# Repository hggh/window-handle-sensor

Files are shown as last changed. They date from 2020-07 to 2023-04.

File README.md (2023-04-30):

### window handle sensor

get the status of your windows. sensor is between your handle and the window.

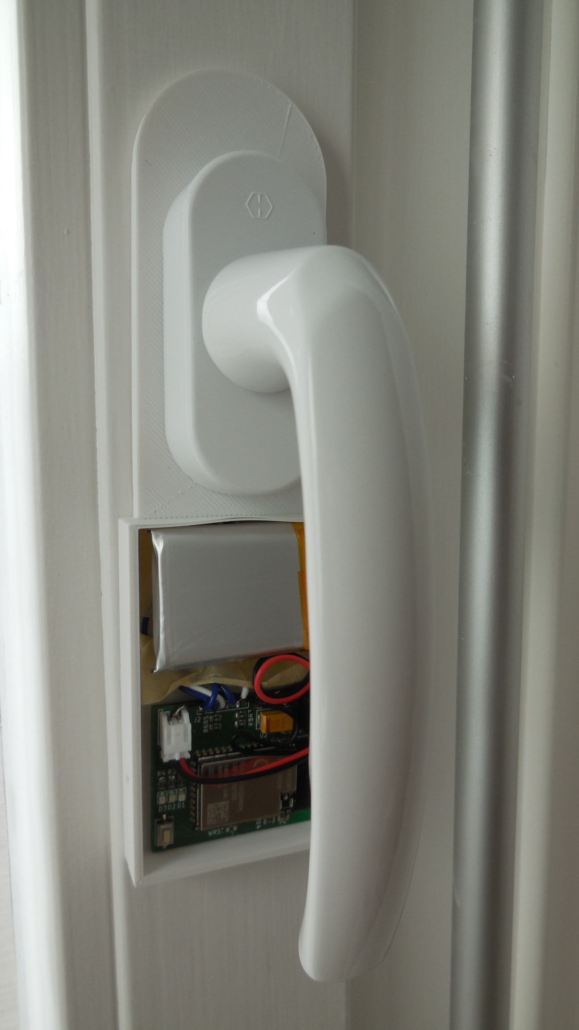
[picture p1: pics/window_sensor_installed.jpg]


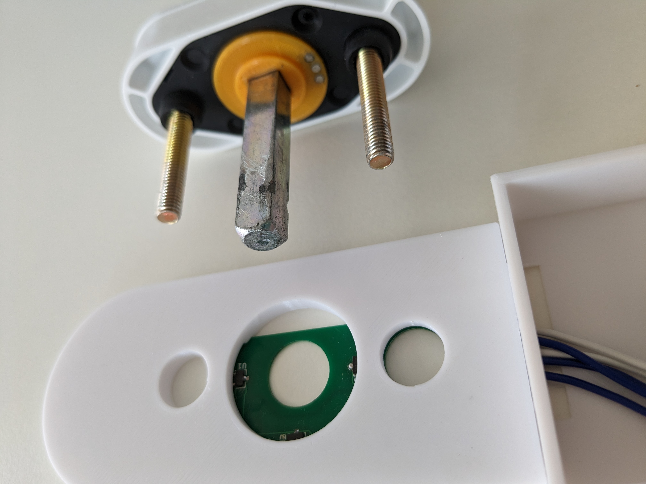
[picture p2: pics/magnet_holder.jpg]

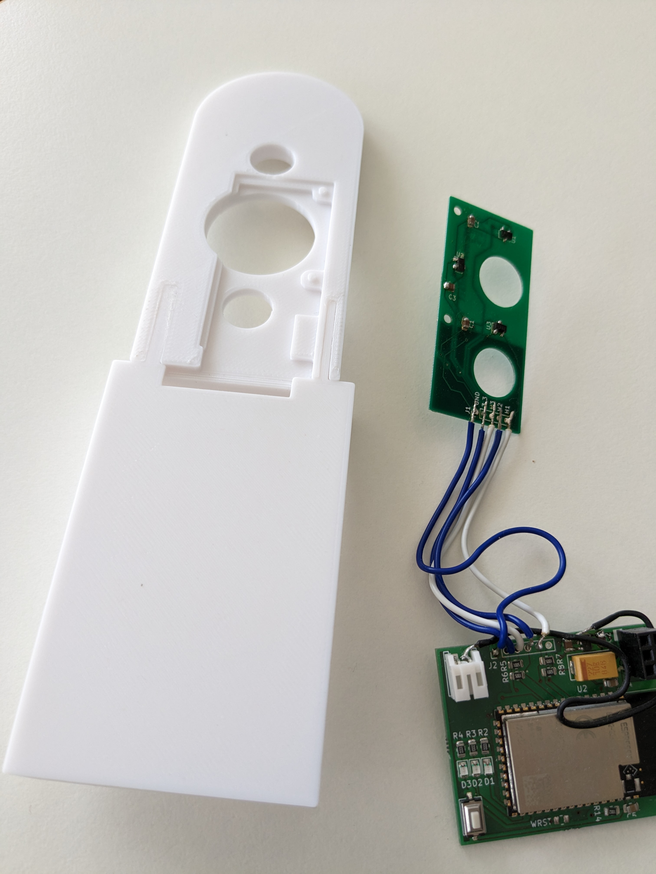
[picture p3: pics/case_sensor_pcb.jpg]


### TODO

 * replace xc6220 footprint with the one from KiCAD
 * add a button for wifi reset
 * battery connector rotate it: open should be on top

### PCBs

this project contains of two pcbs.

#### window-handle-sensor

This PCB is the sensor. It has three hall sensors placed on a **0.6mm** pcb.

library used: https://github.com/hggh/kicad-libraries

##### BOM of window-handle-sensor pcb

| number | name |
|---| ---|
| C1,C2,C3 | ceramic cap 0.1 µF SMD 0805 |
| U1,U2,U3 | Infineon TLE4913 |

#### ESP controller board

This PCB is the controller board with the ESP32-S2. The thickness of this pcb can be 1.0-1.6mm.

##### BOM of esp32-s2 pcb

| number | name |
|--- | ---|
| C1 | ceramic cap 22µF SMD 0805 |
| C2 | ceramic cap 4.7µF SMD 0805 |
| C3 | tantalum cap 220µF SMD EIA-7343-31 |
| C4 | ceramic cap 100nF SMD 0805 |
| C5 | ceramic cap 1µF SMD 0805 |
| U1 | XC6220 3.0V SOT-25 |
| U2 | ESP32-S2-WROOM |
| H1 | 2.54mm 2x3 pin header |
| J1 | JST PH S2B-PH-K |
| Q1 | BC817 |
| Q2 | BC807 |
| R1, R14 | 10k SMD0805 |
| R2, R3, R4 | 100 SMD0805 |
| R5, R6, R7, R8, R9 | 10M SMD 0805 |
| R10, R11 | 1k1 SMD 0805 |
| R12, R13 | 10k SMD 0805 |

### case

The inlay is placed on the square bolt with 3x magnets.

Magnets: Ø 2 mm, h=1mm (strength: 110g): https://www.supermagnete.de/eng/disc-magnets-neodymium/disc-magnet-2mm-1mm_S-02-01-N

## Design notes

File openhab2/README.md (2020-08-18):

### OpenHAB2 integration

OpenHAB2 2.4 and later are required!

### install plugins

for the OpenHAB2 integration you will need to install the OpenHAB2 plugins (e.g. via paperui)

* MQTT Binding

#### install files into OpenHAB2 installation

```
cp *.items items/
cp *.map transform/
cp *.rules rules/
cp *.things things/
 ```
 
#### configuration

open **rules/window-state.things** and configure *host*, *username* and *password* parameter.

For every new Window state device you need:
 
 * **rules/window-state.things**: copy the "Thing topic window1" block and count the number "1" up. Also replace the "1" in the *stateTopic*!
 * **items/window-state.items**: copy the last three lines and also count the number "1" up. Do not rename the Item names. They are needed for the rules. But update the label of the item.
 
 The rules are based on the Item Groups - every Item that is also placed in the same groups all alarm rules will work on the fly! 
 
 Inside the **rules(window-state.rules** file you can configure how you will be notified if the battery is low or the device was not active within the last 25 hours.
 See line 49 and 63 inside the rules file. If you want to use Telegram, please install the Telegram plugin and configure your bot and enable the lines.

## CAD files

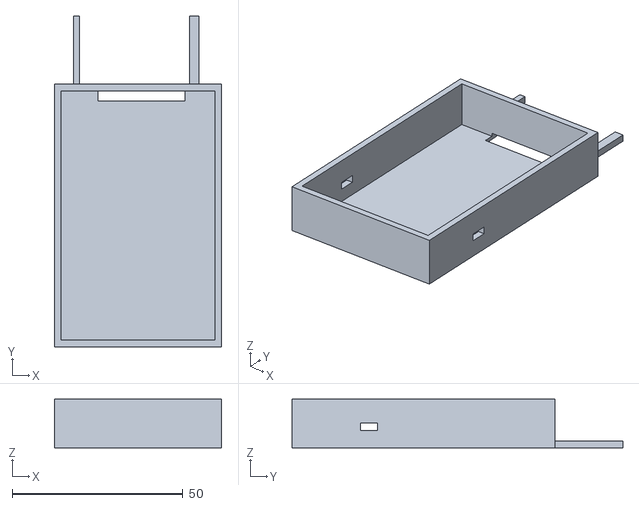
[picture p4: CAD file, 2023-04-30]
case/case_battery.stl
49.0 x 96.9 x 14.2

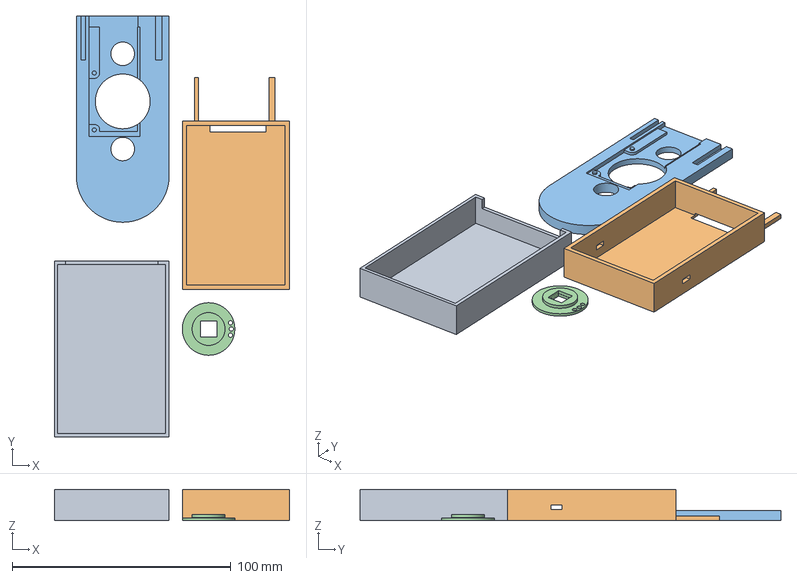
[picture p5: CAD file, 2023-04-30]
case/case.3mf
107.4 x 192.3 x 14.2 mm
battery_lid.stl
case_battery.stl
case_top.stl
inlay.stl

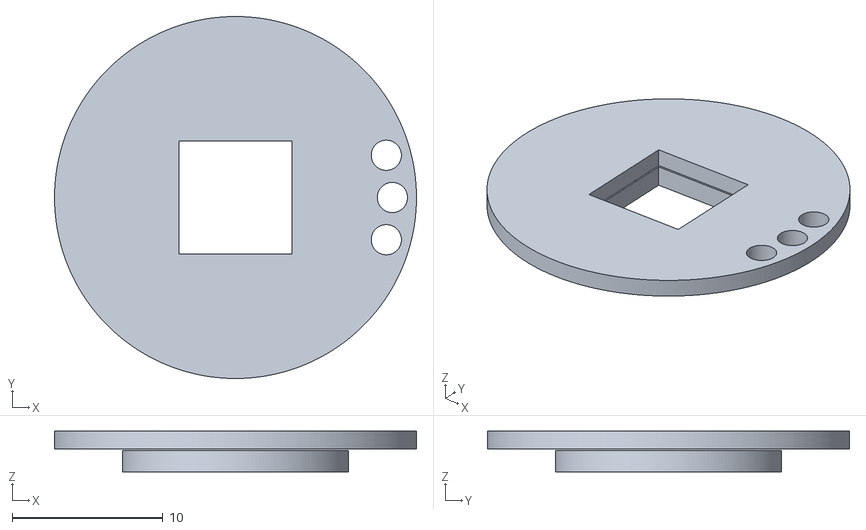
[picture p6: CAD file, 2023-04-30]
case/inlay.stl
24.0 x 24.0 x 2.70

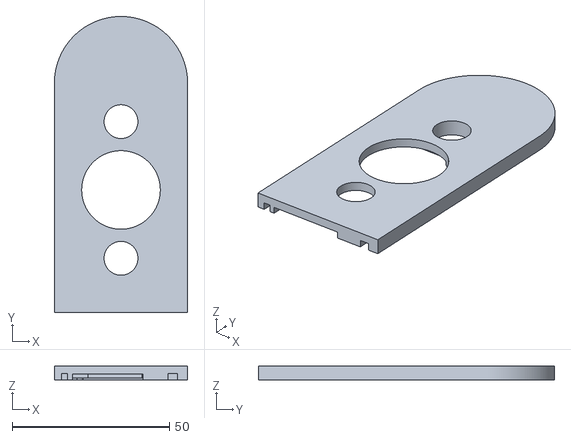
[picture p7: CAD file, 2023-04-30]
case/case_top.stl
42.4 x 94.2 x 4.50

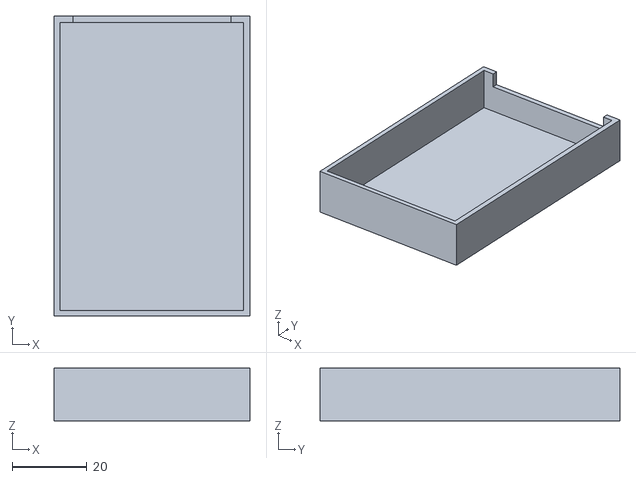
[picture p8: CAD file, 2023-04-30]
case/battery_lid.stl
52.4 x 80.4 x 14.2

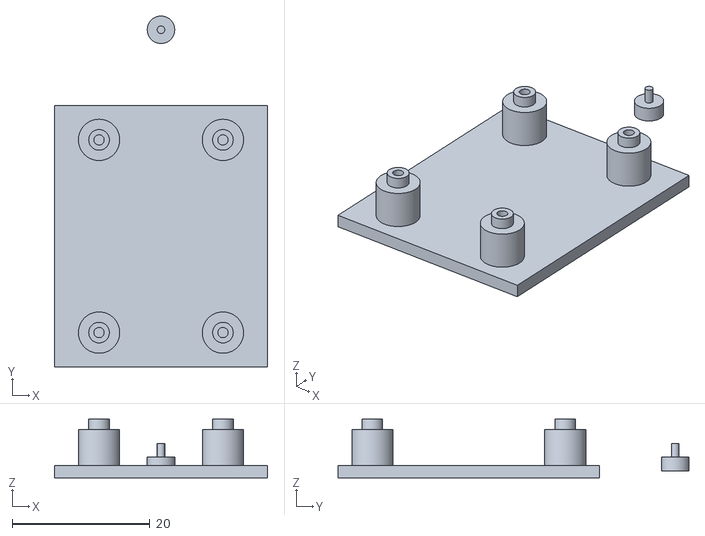
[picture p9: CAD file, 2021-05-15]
case/lipo-loader.stl
31.0 x 51.0 x 8.50

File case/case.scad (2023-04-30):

VIERKANT = 7.5;
CASE_SIZE_X = 40;
CASE_SIZE_Y = 68;
BOHRUNG_ABSTAND_MITTE = 21.75;
BOHRUNGEN = 10.75;

PCB_SIZE_X = 23.5;
PCB_SIZE_Y = 50;
PCB_SIZE_Z = 0.6 + 0.1;
PCB_SIZE_PARTS_Z = 1.2;

INLAY_HEIGHT_SPACING_Y = 1.4;
INLAY_HEIGHT_HOLDER_MAGNET_Y = 1.2;

CASE_SIZE_Z = PCB_SIZE_Z + INLAY_HEIGHT_SPACING_Y + INLAY_HEIGHT_HOLDER_MAGNET_Y;

BATTERY_BOX_X = 45 + 2 + 2;
BATTERY_BOX_Y = 75 + 2;
BATTERY_BOX_Z = 13;

LID_BATTERY_BOX_X = BATTERY_BOX_X + 1.6 + 1.6 + 0.1 + 0.1;
LID_BATTERY_BOX_Y = BATTERY_BOX_Y + 1.6 + 1.6 + 0.1 + 0.1;
LID_BATTERY_BOX_Z = BATTERY_BOX_Z + 1.2;


module pcb() {
    cube([PCB_SIZE_X, PCB_SIZE_Y, PCB_SIZE_Z+1]);
    // PCB the SMD stuff on front
    
    cube([22.25, PCB_SIZE_Y-2.25, PCB_SIZE_Z + PCB_SIZE_PARTS_Z+1]);
    translate([0, -5, 0]) cube([22.5, 5, PCB_SIZE_Z + PCB_SIZE_PARTS_Z+1]);
}

module inlay() {
	difference(){
        union() {
            cylinder(h=INLAY_HEIGHT_SPACING_Y, r=7.5, $fn=180);
            translate([0, 0, 1.5]) {
                cylinder(h=INLAY_HEIGHT_HOLDER_MAGNET_Y, r=12, $fn=180);
            }
        }
		cube([VIERKANT, VIERKANT, 10], center=true);
		translate([10.4, 0, -1]) {
			cylinder(h=20, d=2, $fn=180);
		}
        translate([10.0, 2.8, -1]) {
			cylinder(h=20, d=2, $fn=180);
		}
        translate([10.0, -2.8, -1]) {
			cylinder(h=20, d=2, $fn=180);
		}
	}
}

module lid() {

    difference() {
        cube([LID_BATTERY_BOX_X, LID_BATTERY_BOX_Y, LID_BATTERY_BOX_Z]);
        translate([1.6 - 0.1, 1.6 - 0.1, 1.2]) {
            cube([BATTERY_BOX_X + 0.1 + 0.1, BATTERY_BOX_Y + 0.1 + 0.1, 20]);
        }
        translate([(LID_BATTERY_BOX_X/2 - (CASE_SIZE_X + 2.4)/2), LID_BATTERY_BOX_Y-2, LID_BATTERY_BOX_Z - (CASE_SIZE_Z + 1.2) ]) {
            cube([CASE_SIZE_X + 2.4, 20, 20]);
        }
    }
}

module box_pcb_battery() {
    // innen: 45mm x 75mm
    difference() {
        cube([BATTERY_BOX_X, BATTERY_BOX_Y, LID_BATTERY_BOX_Z]);
        translate([2, 2, 1]) {
            cube([45, 73, LID_BATTERY_BOX_Z]);
        }
        translate([BATTERY_BOX_X/2 - PCB_SIZE_X/2, BATTERY_BOX_Y - 5, 0]) {
            cube([PCB_SIZE_X+2, 6, 2]);
        }
        translate([-1, 20, 5]) {
            cube([100, 5, 2.2]);
        }
        
    }
    translate([BATTERY_BOX_X/2, BATTERY_BOX_Y, 0]) {
        translate([15+0.1, 0, 0]) cube([3-0.2, 20-0.1, 2]);
        translate([-19+0.1, 0, 0]) cube([2-0.2, 20-0.1, 2]);
    }
    
}


module case_top() {
    difference() {
        union() {
            translate([0, CASE_SIZE_Y/2, 0]) {
                cylinder(h=CASE_SIZE_Z + 1.2, d=CASE_SIZE_X + 2.4, $fn=190);
            }
            translate([-(CASE_SIZE_X/2)-1.2, -(CASE_SIZE_Y/2) -5 , 0]) {
                cube([CASE_SIZE_X + 2.4, CASE_SIZE_Y+5, CASE_SIZE_Z + 1.2]);
            }
        }
        
        // Bohrung Mitte
        translate([0, 0, -1]) cylinder(h=10, d=25, $fn=180);
        // Bohrung Oben
        translate([0, BOHRUNG_ABSTAND_MITTE, -1]) cylinder(h=10, d=BOHRUNGEN, $fn=180);
        // Bohrung Unten
        translate([0, - BOHRUNG_ABSTAND_MITTE, -1]) cylinder(h=10, d=BOHRUNGEN, $fn=180);


        translate([-15.5, -34, -1]) {
            pcb();
        }
        
        // Ankerpunkte Batterie PCB Box
        translate([0, -(CASE_SIZE_Y/2) -5, 0]) {
            translate([15, 0, 0]) cube([3, 20, 2 +0.1]);
            translate([-19, 0, 0]) cube([2, 20, 2+0.1]);
        }
    }
    
    translate([-15.5, -34, 0]) {
        translate([0, 0, PCB_SIZE_Z]) {
            cube([5, 21, PCB_SIZE_PARTS_Z]);
        }
    }
    // haltepunkte PCB
    translate([-13, 13, 0]) {
        cylinder(h=CASE_SIZE_Z, d=1.9, $fn=180);
        translate([0, 0, PCB_SIZE_Z]) {
            cylinder(h=CASE_SIZE_Z-PCB_SIZE_Z, d=5, $fn=190);
            translate([-5, -2.5, 0]) cube([5, 5, CASE_SIZE_Z-PCB_SIZE_Z]);
        }
    }
    translate([-13, -13, 0]) {
        cylinder(h=CASE_SIZE_Z, d=1.9, $fn=180);
        translate([0, 0, PCB_SIZE_Z]) {
            cylinder(h=CASE_SIZE_Z-PCB_SIZE_Z, d=5, $fn=180);
            
            translate([-5, -2.5, 0]) cube([5, 5, CASE_SIZE_Z-PCB_SIZE_Z]);
        }
    }

}



translate([50, 10, 0]) {
    inlay();
}

translate([0, 10, 0]) {
    case_top();
}


translate([100, 0, 0]) {
    box_pcb_battery();
}

translate([155, -1.6, 0]) {
    lid();
}

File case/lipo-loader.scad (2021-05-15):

$fn = 190;

module holder() {
    difference() {
        union() {
            cylinder(d=6, h=6);
            cylinder(d=3, h=7.5);
        }
        
        translate([0, 0, 5]) {
            cylinder(d=1.5, h=10);
        }
    }
}

module pin() {
    cylinder(h=2, d=4);
    cylinder(d=1.1, h=4);
}


translate([-15.5, -19, -1]) {
    cube([31, 38, 1.8]);
}
translate([9, 14, 0]) holder();
translate([9, -14, 0]) holder();
translate([-9, 14, 0]) holder();
translate([-9, -14, 0]) holder();

translate([0, 30, 0]) pin();

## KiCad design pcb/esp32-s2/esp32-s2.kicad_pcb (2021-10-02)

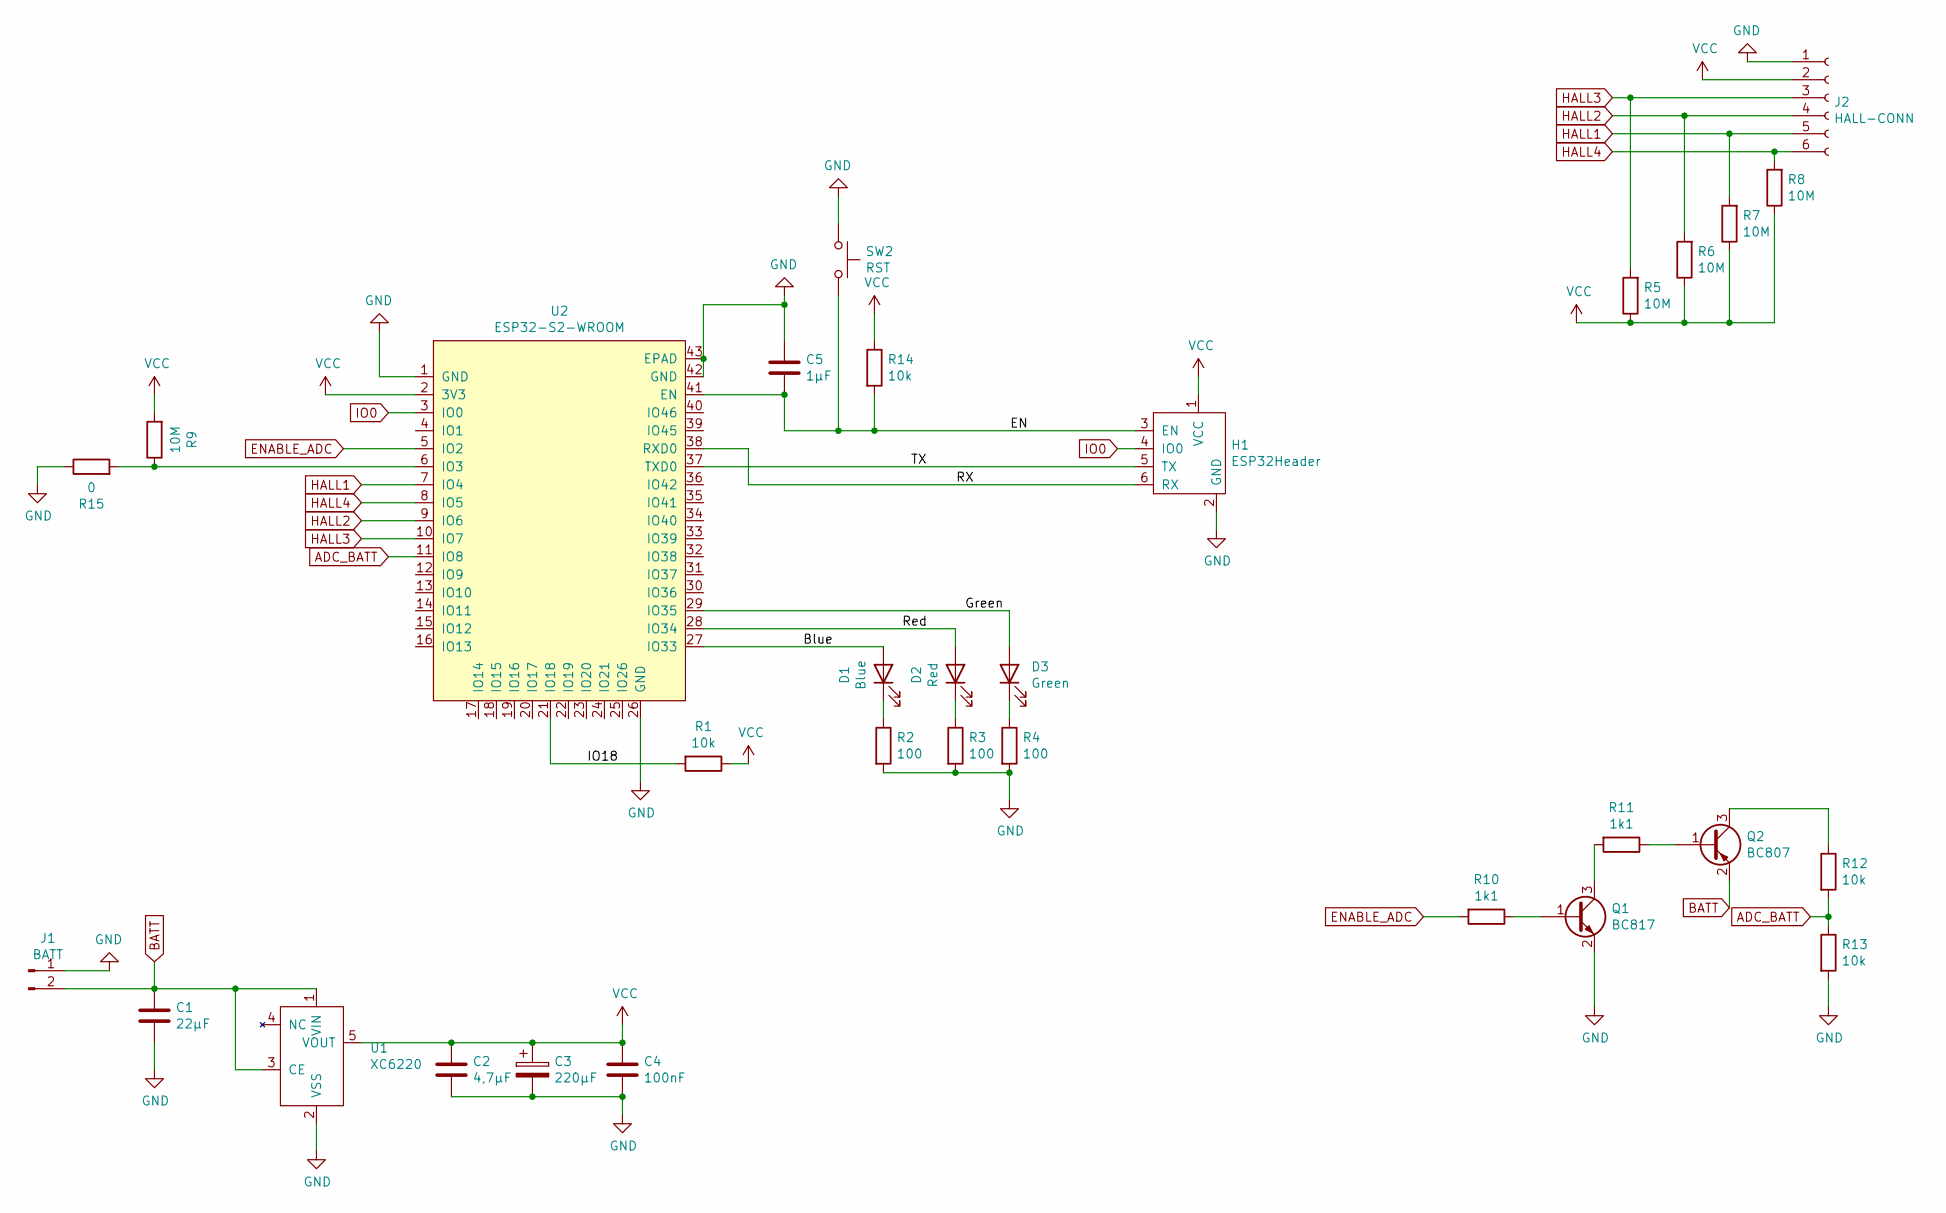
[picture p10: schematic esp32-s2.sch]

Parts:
C1: 22µF; C_0805_2012Metric
C2: 4,7µF; C_0805_2012Metric
C3: 220µF; CP_EIA-7343-31_Kemet-D
C4: 100nF; C_0805_2012Metric
C5: 1µF; C_0805_2012Metric
D1: Blue; LED_0805_2012Metric
D2: Red; LED_0805_2012Metric
D3: Green; LED_0805_2012Metric
H1: ESP32Header; esp32-prog-header
J1: BATT; JST_PH_S2B-PH-K_1x02_P2.00mm_Horizontal
J2: HALL-CONN; PinHeader_1x06_P2.00mm_Vertical
Q1: BC817; SOT-23
Q2: BC807; SOT-23
R1, R12, R13: 10k; R_0805_2012Metric
R2, R3, R4: 100; R_0805_2012Metric
R5, R6, R7, R8, R9: 10M; R_0805_2012Metric
R10, R11: 1k1; R_0805_2012Metric
R14: 10k; C_0805_2012Metric
R15: 0; R_0805_2012Metric
SW2: RST; SMD_Button
U1: XC6220
U2: ESP32-S2-WROOM

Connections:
/Blue: D1.2 (A), U2.27 (IO33)
/EN: C5.2, H1.3 (EN), R14.2, SW2.2, U2.41 (EN)
/Green: D3.2 (A), U2.29 (IO35)
/IO18: R1.2, U2.21 (IO18)
/RX: H1.6 (RX), U2.38 (RXD0)
/Red: D2.2 (A), U2.28 (IO34)
/TX: H1.5 (TX), U2.37 (TXD0)
ADC_BATT: R12.2, R13.1, U2.11 (IO8)
BATT: C1.1, J1.2, Q2.2 (E), U1.1 (VIN), U1.3 (CE)
ENABLE_ADC: R10.2, U2.5 (IO2)
GND: C1.2, C2.2, C3.2, C4.2, C5.1, H1.2 (GND), J1.1, J2.1, Q1.2 (E), R2.2, R3.2, R4.2, R13.2, R15.1, SW2.1, U1.2 (VSS), U2.1 (GND), U2.26 (GND), U2.42 (GND), U2.43 (EPAD)
HALL1: J2.5, R7.2, U2.7 (IO4)
HALL2: J2.4, R6.2, U2.9 (IO6)
HALL3: J2.3, R5.2, U2.10 (IO7)
HALL4: J2.6, R8.2, U2.8 (IO5)
IO0: H1.4 (IO0), U2.3 (IO0)
unnamed: D1.1 (K), R2.1
unnamed: D2.1 (K), R3.1
unnamed: D3.1 (K), R4.1
unnamed: Q1.1 (B), R10.1
unnamed: Q1.3 (C), R11.2
unnamed: Q2.1 (B), R11.1
unnamed: Q2.3 (C), R12.1
unnamed: R9.1, R15.2, U2.6 (IO3)
VCC: C2.1, C3.1, C4.1, H1.1 (VCC), J2.2, R1.1, R5.1, R6.1, R7.1, R8.1, R9.2, R14.1, U1.5 (VOUT), U2.2 (3V3)

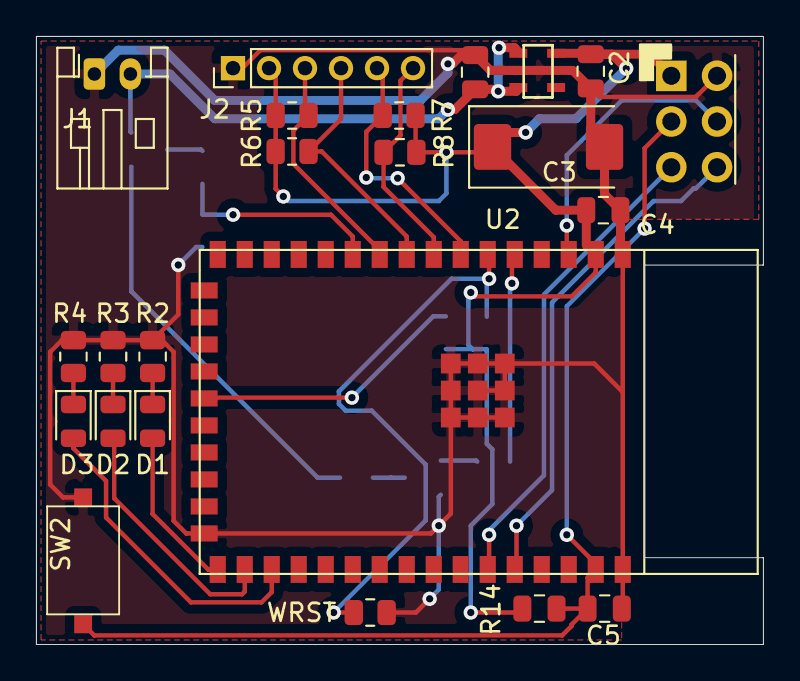
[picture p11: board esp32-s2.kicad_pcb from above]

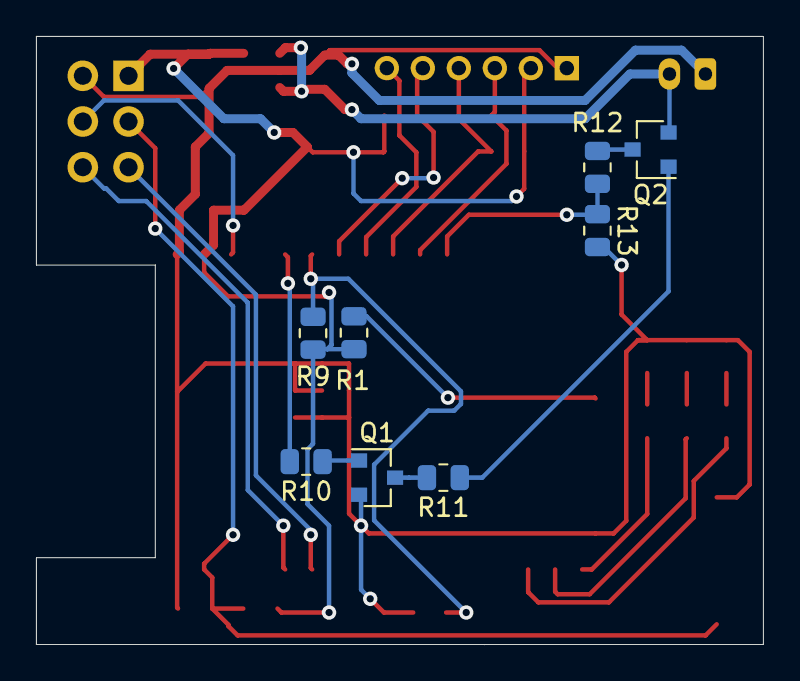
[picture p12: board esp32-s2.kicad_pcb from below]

Board: 2 copper layers, 40.4 x 33.8 mm, 31 parts (8 on the bottom side), 25 nets.

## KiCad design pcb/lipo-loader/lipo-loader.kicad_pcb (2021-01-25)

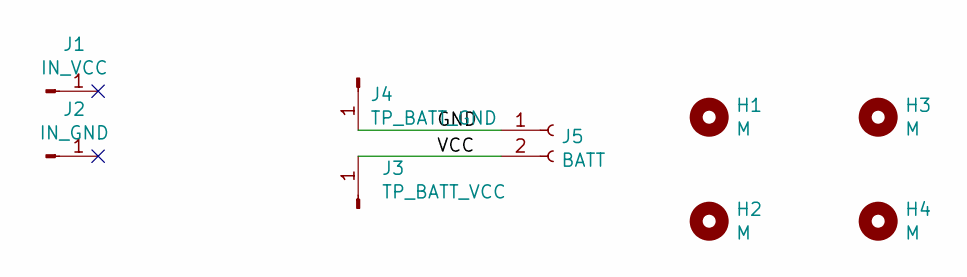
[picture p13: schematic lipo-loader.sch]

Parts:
H1, H2, H3, H4: M; MountingHole_3.2mm_M3
J1: IN_VCC; PinHeader_1x01_P2.54mm_Vertical
J2: IN_GND; PinHeader_1x01_P2.54mm_Vertical
J3: TP_BATT_VCC; PinHeader_1x01_P2.54mm_Vertical
J4: TP_BATT_GND; PinHeader_1x01_P2.54mm_Vertical
J5: BATT; JST_PH_S2B-PH-K_1x02_P2.00mm_Horizontal

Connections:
/GND: J4.1, J5.1
/VCC: J3.1, J5.2

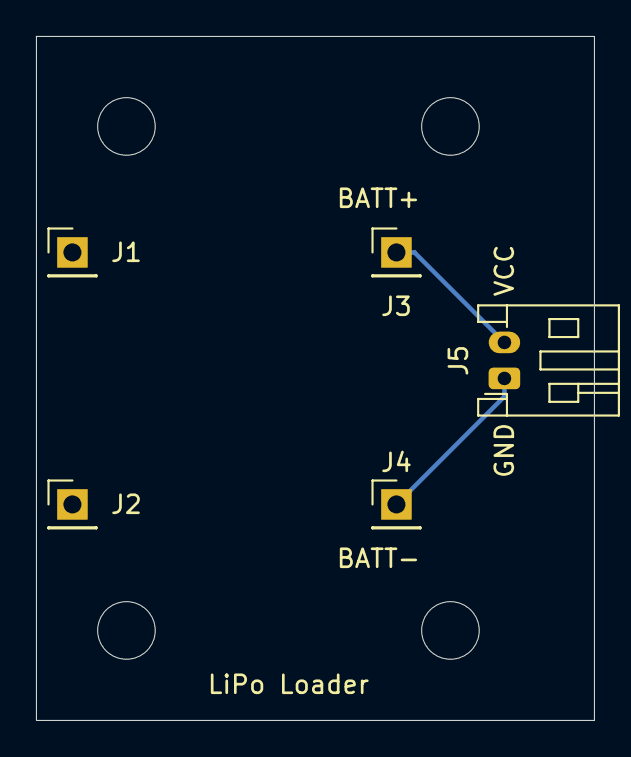
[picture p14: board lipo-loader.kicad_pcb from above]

Board: 2 copper layers, 31.0 x 38.0 mm, 9 parts (0 on the bottom side), 2 nets.

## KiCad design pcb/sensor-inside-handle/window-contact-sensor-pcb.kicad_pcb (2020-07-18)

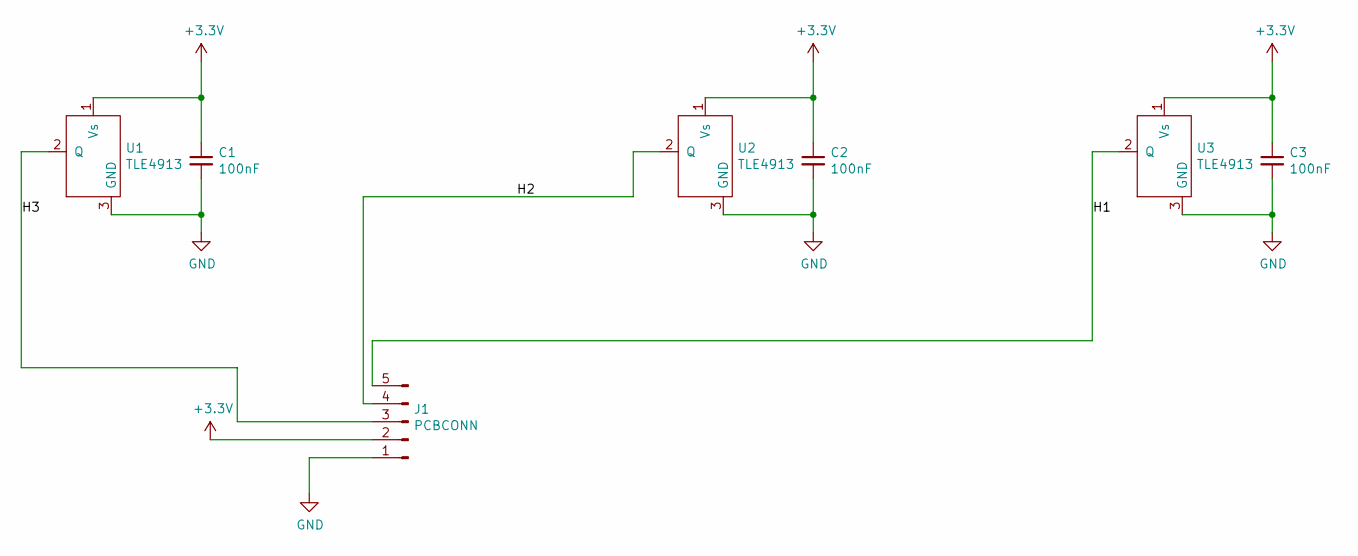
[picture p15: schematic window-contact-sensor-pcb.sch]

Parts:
C1, C2, C3: 100nF; C_0805_2012Metric
J1: PCBCONN; PinHeader_1x05_P2.00mm_Vertical
U1, U2, U3: TLE4913; SC-59

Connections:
+3V3: C1.1, C2.1, C3.1, J1.2, U1.1 (Vs), U2.1 (Vs), U3.1 (Vs)
/H1: J1.5, U3.2 (Q)
/H2: J1.4, U2.2 (Q)
/H3: J1.3, U1.2 (Q)
GND: C1.2, C2.2, C3.2, J1.1, U1.3 (GND), U2.3 (GND), U3.3 (GND)

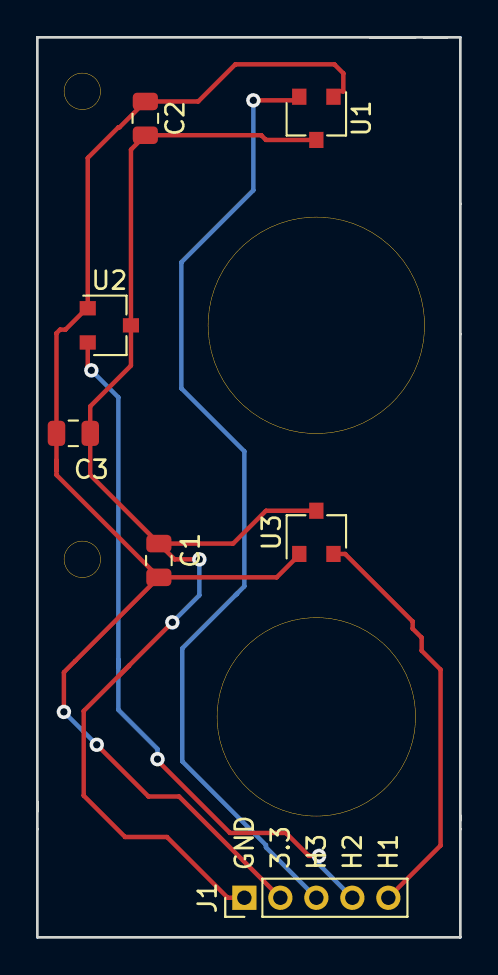
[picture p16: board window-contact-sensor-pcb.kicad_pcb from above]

Board: 2 copper layers, 23.5 x 50.0 mm, 7 parts (0 on the bottom side), 5 nets.

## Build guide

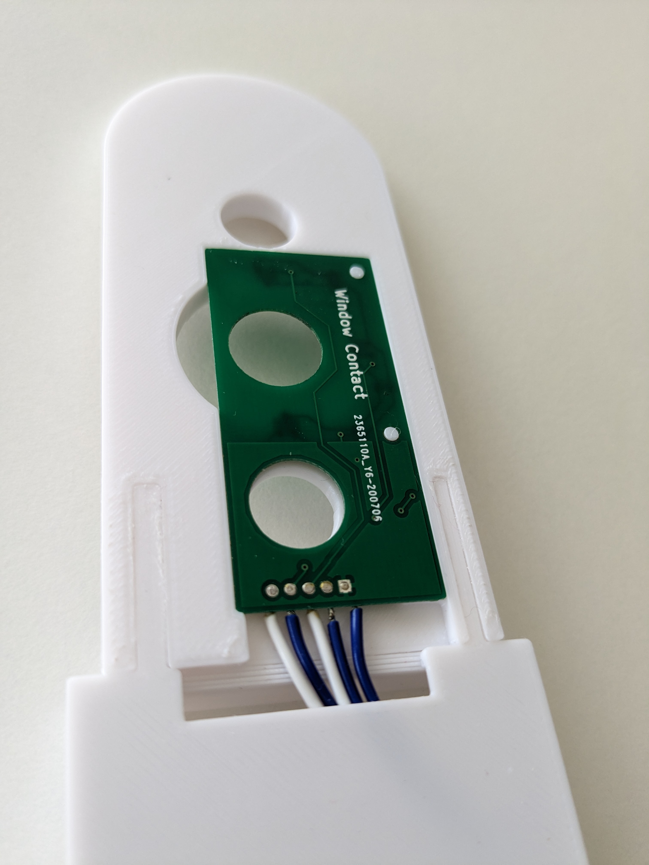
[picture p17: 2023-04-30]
pics/case_sensor_pcb_installed.jpg

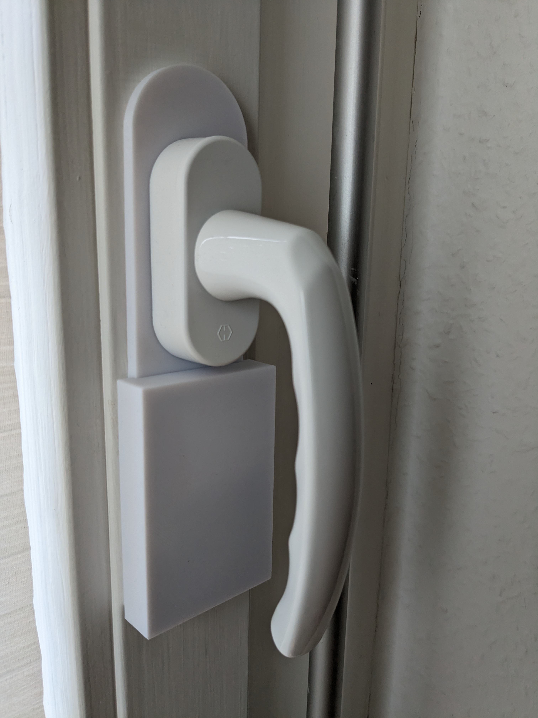
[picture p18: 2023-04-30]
pics/installed_with_lid.jpg

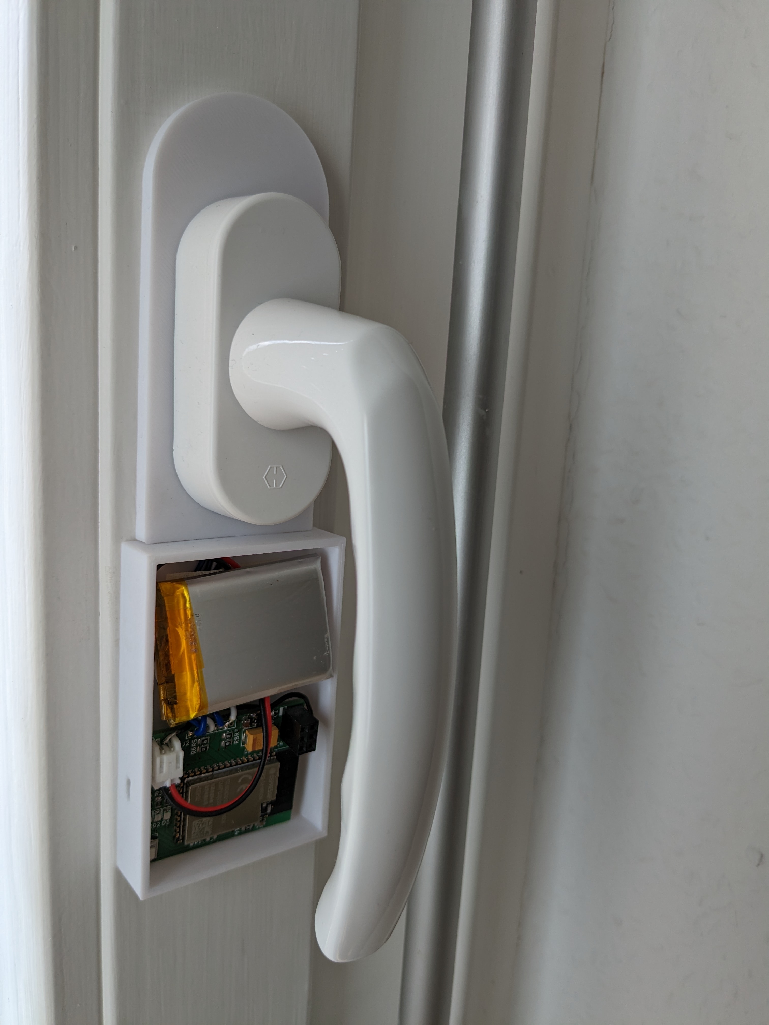
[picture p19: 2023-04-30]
pics/installed.jpg

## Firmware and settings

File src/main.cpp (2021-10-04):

#include "driver/gpio.h"
#include "driver/rtc_io.h"
#include "esp_sleep.h"
#include <driver/adc_common.h>
#include "driver/adc.h"
#include "esp_adc_cal.h"
#include "esp_wifi.h"

#include <Arduino.h>

#include <WiFi.h>
#include <MQTT.h>

#define uS_TO_S_FACTOR 1000000

#define LED_GREEN GPIO_NUM_35
#define LED_RED GPIO_NUM_34
#define LED_BLUE GPIO_NUM_33
#define HALL_SENSOR_1 GPIO_NUM_4
#define HALL_SENSOR_2 GPIO_NUM_6
#define HALL_SENSOR_3 GPIO_NUM_7

#define DEFAULT_VREF    1100
#define NO_OF_SAMPLES   10

static esp_adc_cal_characteristics_t adc_chars;
static const adc_channel_t channel = ADC_CHANNEL_7;
static const adc_bits_width_t width = ADC_WIDTH_BIT_13;
static const adc_atten_t atten = ADC_ATTEN_DB_11;

#define BATTERY_ENABLE_ADC GPIO_NUM_2
#define ADC_GPIO_PIN GPIO_NUM_8
//#define ADC_GPIO_PIN_ARDUINO 8
static float volt_r1 = 10000.0;
static float volt_r2 = 10000.0;

#define WINDOW_HANDLE_RIGHT 1
#define WINDOW_HANDLE_LEFT 2

#define WINDOW_STATUS_UNDEFINED 0
#define WINDOW_STATUS_CLOSED 2
#define WINDOW_STATUS_OPENED 4
#define WINDOW_STATUS_HALF_OPENED 6

#include "config.h"

/*
 * global vars
 */
RTC_DATA_ATTR unsigned int bootCount = 0;
MQTTClient mqtt;
WiFiClient net;
esp_sleep_source_t w_cause;

float get_battery_voltage() {
  adc_power_acquire();

  rtc_gpio_hold_dis(BATTERY_ENABLE_ADC);
  gpio_reset_pin(BATTERY_ENABLE_ADC);
  gpio_reset_pin(ADC_GPIO_PIN);

  gpio_set_direction(BATTERY_ENABLE_ADC, GPIO_MODE_OUTPUT);
  gpio_set_direction(ADC_GPIO_PIN, GPIO_MODE_INPUT);
  gpio_set_level(BATTERY_ENABLE_ADC, 1);

  adc1_config_width(width);
  adc1_config_channel_atten((adc1_channel_t)channel, atten);

  esp_adc_cal_characterize(ADC_UNIT_1, atten, width, DEFAULT_VREF, &adc_chars);

  uint32_t adc_reading = 0;
  for (int i = 0; i < NO_OF_SAMPLES; i++) {
    adc_reading += adc1_get_raw((adc1_channel_t)channel);
  }
  adc_reading /= NO_OF_SAMPLES;
  // get mV
  uint32_t voltage = esp_adc_cal_raw_to_voltage(adc_reading, &adc_chars);
  float battery_voltage = (voltage / 1000.0) / (volt_r2 / ( volt_r1 + volt_r2));

  gpio_set_level(BATTERY_ENABLE_ADC, 0);
  adc_power_release();
  return battery_voltage;
}


void connect_mqtt() {
  mqtt.connect(HOSTNAME, MQTT_USERNAME, MQTT_PASSWORD);
}

void setup_hall_sensor_pins() {
  rtc_gpio_deinit(HALL_SENSOR_1);
  gpio_pullup_dis(HALL_SENSOR_1);
  gpio_pulldown_dis(HALL_SENSOR_1);
  gpio_set_direction(HALL_SENSOR_1, GPIO_MODE_INPUT);

  rtc_gpio_deinit(HALL_SENSOR_2);
  gpio_pullup_dis(HALL_SENSOR_2);
  gpio_pulldown_dis(HALL_SENSOR_2);
  gpio_set_direction(HALL_SENSOR_2, GPIO_MODE_INPUT);

  rtc_gpio_deinit(HALL_SENSOR_3);
  gpio_pullup_dis(HALL_SENSOR_3);
  gpio_pulldown_dis(HALL_SENSOR_3);
  gpio_set_direction(HALL_SENSOR_3, GPIO_MODE_INPUT);
}

uint8_t get_window_status() {
  uint8_t hall1_status = gpio_get_level(HALL_SENSOR_1);
  uint8_t hall2_status = gpio_get_level(HALL_SENSOR_2);
  uint8_t hall3_status = gpio_get_level(HALL_SENSOR_3);

  if (window_handle == WINDOW_HANDLE_RIGHT) {
    if (hall1_status == 0 && hall2_status == 1 && hall3_status == 1) {
      return WINDOW_STATUS_CLOSED;
    }
    if (hall1_status == 1 && hall2_status == 0 && hall3_status == 1) {
      return WINDOW_STATUS_OPENED;
    }
    if (hall1_status == 1 && hall2_status == 1 && hall3_status == 0) {
      return WINDOW_STATUS_HALF_OPENED;
    }
  }
  else {
    if (hall1_status == 1 && hall2_status == 1 && hall3_status == 0) {
      return WINDOW_STATUS_CLOSED;
    }
    if (hall1_status == 1 && hall2_status == 0 && hall3_status == 1) {
      return WINDOW_STATUS_OPENED;
    }
    if (hall1_status == 0 && hall2_status == 1 && hall3_status == 1) {
      return WINDOW_STATUS_HALF_OPENED;
    }
  }
  return WINDOW_STATUS_UNDEFINED;
}

void setup_leds() {
  gpio_set_direction(LED_GREEN, GPIO_MODE_OUTPUT);
  gpio_set_direction(LED_RED, GPIO_MODE_OUTPUT);
  gpio_set_direction(LED_BLUE, GPIO_MODE_OUTPUT);
}

void led_on(gpio_num_t led) {
  gpio_set_level(led, 1);
}

void led_off(gpio_num_t led) {
  gpio_set_level(led, 0);
}

bool send_window_status(int window_status) {
  if (mqtt.publish(String("/ws/" + String(MQTT_TOPIC_ID) + "/state").c_str(), String(window_status).c_str(), false, 2)) {
    led_on(LED_GREEN);
    delay(5);
    return true;
  }
  return false;
}

bool send_boot_count(unsigned int boot_count) {
  return mqtt.publish(String("/ws/" + String(MQTT_TOPIC_ID) + "/boot_count").c_str(), String(boot_count).c_str(), false, 2);
}

bool send_battery_voltage(float battery_voltage) {
  return mqtt.publish(String("/ws/" + String(MQTT_TOPIC_ID) + "/battery").c_str(), String(battery_voltage).c_str(), false, 2);
}

int set_deep_sleep_wakeup() {
  gpio_num_t gpio_current_low;
  if (gpio_get_level(HALL_SENSOR_1) == 0) {
    gpio_current_low = HALL_SENSOR_1;
  }
  else if (gpio_get_level(HALL_SENSOR_2) == 0) {
    gpio_current_low = HALL_SENSOR_2;
  }
  else if (gpio_get_level(HALL_SENSOR_3) == 0) {
    gpio_current_low = HALL_SENSOR_3;
  }
  else {
    return -1;
  }

  esp_sleep_enable_ext0_wakeup(gpio_current_low, 1);
  return 0;
}

void goto_deep_sleep() {
  mqtt.disconnect();
#ifdef DEBUG
  Serial.println("Going to deep sleep....");
#endif

  led_off(LED_RED);
  led_off(LED_GREEN);
  led_off(LED_BLUE);

  rtc_gpio_isolate(HALL_SENSOR_1);
  rtc_gpio_isolate(HALL_SENSOR_2);
  rtc_gpio_isolate(HALL_SENSOR_3);
  rtc_gpio_isolate(BATTERY_ENABLE_ADC);
  rtc_gpio_isolate(ADC_GPIO_PIN);

  esp_wifi_stop();
  adc_power_off();
  esp_sleep_enable_timer_wakeup((uint64_t)(60 * 60 * 24) * (uint64_t)uS_TO_S_FACTOR);
  esp_deep_sleep_start();
}

void setup() {
#ifdef DEBUG
  Serial.begin(115200);
#endif
  ++bootCount;
  w_cause = esp_sleep_get_wakeup_cause();
  esp_deep_sleep_disable_rom_logging();
  esp_sleep_disable_wakeup_source(ESP_SLEEP_WAKEUP_ALL);

  if (w_cause != ESP_SLEEP_WAKEUP_TIMER) {
    led_on(LED_BLUE);
  }

  setup_leds();
  setup_hall_sensor_pins();

  WiFi.setHostname(HOSTNAME);
  WiFi.mode(WIFI_STA);
  WiFi.begin(SECRET_SSID, SECRET_PASS);

  mqtt.begin(MQTT_SERVER, net);

  int wifi_conn_status = 0;
  while (WiFi.status() != WL_CONNECTED) {
    delay(1);
    wifi_conn_status++;

    if (wifi_conn_status > 4000) {
#ifdef DEBUG
      Serial.println("Could not connect to wifi after 4000ms ... restart");
#endif
      ESP.restart();
    }
  }
  led_off(LED_BLUE);
  connect_mqtt();

  uint8_t window_state = get_window_status();
#ifdef DEBUG
    Serial.print("Window State is: ");
    Serial.println(window_state);
    Serial.print("Boot count: ");
    Serial.println(bootCount);
#endif
  if (send_window_status(window_state) == false) {
    led_on(LED_RED);
    delay(10);
    send_window_status(window_state);
  }
  send_boot_count(bootCount);
  send_battery_voltage(get_battery_voltage());
  mqtt.loop();

  if (set_deep_sleep_wakeup() == 0) {
    goto_deep_sleep();
  }
}

void loop() {
  led_off(LED_BLUE);
  led_off(LED_GREEN);
  led_on(LED_RED);
  gpio_wakeup_enable(HALL_SENSOR_1, gpio_get_level(HALL_SENSOR_1) == 1 ? GPIO_INTR_LOW_LEVEL : GPIO_INTR_HIGH_LEVEL);
  gpio_wakeup_enable(HALL_SENSOR_2, gpio_get_level(HALL_SENSOR_2) == 1 ? GPIO_INTR_LOW_LEVEL : GPIO_INTR_HIGH_LEVEL);
  gpio_wakeup_enable(HALL_SENSOR_3, gpio_get_level(HALL_SENSOR_3) == 1 ? GPIO_INTR_LOW_LEVEL : GPIO_INTR_HIGH_LEVEL);
  esp_wifi_stop();
  esp_sleep_enable_gpio_wakeup();
  esp_light_sleep_start();
      
  esp_wifi_start();
  esp_sleep_disable_wakeup_source(ESP_SLEEP_WAKEUP_ALL);

  uint8_t window_state = get_window_status();
  int wifi_conn_status = 0;
  if (WiFi.status() != WL_CONNECTED) {
    WiFi.mode(WIFI_STA);
    WiFi.begin(SECRET_SSID, SECRET_PASS);
  }
  while (WiFi.status() != WL_CONNECTED) {
    delay(1);
    wifi_conn_status++;
    if (wifi_conn_status > 4000) {
#ifdef DEBUG
      Serial.println("Could not connect to wifi after 4000ms ... restart");
#endif
      ESP.restart();
    }
  }
  led_off(LED_BLUE);
  connect_mqtt();
  mqtt.loop();

  if (send_window_status(window_state) == false) {
    delay(10);
    send_window_status(window_state);
  }
  send_boot_count(bootCount);
  if (set_deep_sleep_wakeup() == 0) {
    goto_deep_sleep();
  }
}

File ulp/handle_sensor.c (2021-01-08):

#include <stdio.h>
#include <stdint.h>
#include <stdbool.h>
#include "ulp_riscv/ulp_riscv.h"
#include "ulp_riscv/ulp_riscv_utils.h"

#define HALL1_GPIO 4
#define HALL2_GPIO 5
#define HALL3_GPIO 6
#define HALL4_GPIO 7

uint8_t hall1_status_cur;
uint8_t hall2_status_cur;
uint8_t hall3_status_cur;

uint8_t hall1_status;
uint8_t hall2_status;
uint8_t hall3_status;

static inline uint8_t gpio_get_level(uint8_t gpio_num) {
  return (uint8_t)((REG_GET_FIELD(RTC_GPIO_IN_REG, RTC_GPIO_IN_NEXT) & BIT(gpio_num)) ? 1 : 0);
}

int main (void) {
  hall1_status_cur = gpio_get_level(HALL1_GPIO);
  if (hall1_status_cur != hall1_status) {
    hall1_status = hall1_status_cur;
    ulp_riscv_wakeup_main_processor();
  }

  hall2_status_cur = gpio_get_level(HALL2_GPIO);
  if (hall2_status_cur != hall2_status) {
    hall2_status = hall2_status_cur;
    ulp_riscv_wakeup_main_processor();
  }

  hall3_status_cur = gpio_get_level(HALL3_GPIO);
  if (hall3_status_cur != hall3_status) {
    hall3_status = hall3_status_cur;
    ulp_riscv_wakeup_main_processor();
  }

  return 0;
}

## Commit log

2020-07-18 initial commit of sensor pcb with inlay
    [case.scad, window-contact-sensor-pcb.kicad_pcb, window-contact-sensor-pcb.sch]
2020-08-02 initial commit; current 10-12 µA in deep sleep
2020-08-07 add esp32 with ldo
    [esp32-ldo.kicad_pcb, esp32-ldo.sch]
2020-08-07 update pcb size
    [esp32-ldo.kicad_pcb]
2020-08-07 update pcb: rst button
    [esp32-ldo.kicad_pcb]
2020-08-07 fix edge cuts
    [esp32-ldo.kicad_pcb]
2020-08-07 update final pcb
    [esp32-ldo.kicad_pcb]
2020-08-12 wakeup by timer add adc base function
2020-08-13 send battery status, monitor mqtt send
2020-08-13 add openhab2 examples for mqtt and trigger low battery value
2020-08-14 isolate pin before deep sleep. 70µA less
2020-08-18 OpenHab2: add rule to check if sensor was active last 25hours
2020-09-26 use only 3 LEDs for Status green = position known, bloue = position unkown; red = send error
2020-09-26 pcb: removed LED 4
    [esp32-ldo.kicad_pcb, esp32-ldo.sch]
2020-09-27 add stl
    [case.stl]
2021-01-08 work on ESP32-S2
    [esp32-s2.kicad_pcb, esp32-s2.sch]
2021-01-09 update pcb for esp32s2
    [esp32-s2.kicad_pcb, esp32-s2.sch]
2021-01-15 working on ESP32-S2 support
2021-01-16 update pcb: add cap values
    [esp32-s2.kicad_pcb, esp32-s2.sch]
2021-01-18 ESP32-S2 is now working, only ADC does not work yet
    [esp32-ldo.kicad_pcb, esp32-ldo.sch]
2021-01-18 disable wifi and adc on lightsleep
2021-01-18 add lipo loader with tp4056 pcb without protection ICs
    [lipo-loader.kicad_pcb, lipo-loader.sch]
2021-01-21 add boot count of ESP32s2 into openhab, to see if we have resets
2021-01-21 Final Update of LiPO Loader for the sensor
    [lipo-loader.kicad_pcb]
2021-01-25 update lipo loader
    [lipo-loader.kicad_pcb]
2021-02-05 add ADC to query battery voltage
2021-02-07 update footprint for XC6220
    [esp32-s2.kicad_pcb]
2021-02-12 update case
    [case.scad]
2021-02-15 add bom of esp32-s2
2021-02-15 updates case; splitted into two parts
    [case.scad, case.stl]
2021-02-17 add lid
    [case.scad]
2021-05-15 'case' for loader
    [lipo-loader.scad, lipo-loader.stl]
2021-10-02 add todo
    [esp32-s2.kicad_pcb, esp32-s2.sch]
2021-10-03 moved to Arduino framework
